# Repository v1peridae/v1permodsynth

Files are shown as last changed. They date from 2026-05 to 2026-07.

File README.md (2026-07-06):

# This is the v1permodsyth

- A modular sythesiser is an electronic music instrument made of different sythesiser modules! (who wouldve guessed)
- They look something like this:

<p align="center">
  <br>
  <sub>(mine doesn't look as fancy but we're getting somewhere lol)</sub>
</p>

### it currently has:
- square vco
  
  

- vca




- guitar input




-ar




-4lfo




-fm drums




## more on the process
i've never really made anything this complex so i totally understand if it might not work on the first go but i'm really happy with how far i've gotten with this. if you'd like to learn more about the making process check out my JOURNAL.md 

credits to https://www.bartonmusicalcircuits.com/ which is where i learnt how to do all of this :)

casing - it currently doesnt have a case but i have all the measurements and hope to build a wooden or hard cardboard case

note on commits:
guh it totally skipped my mind to make frequent commits of this so i accept my fate if it means my hours get reduced since this is one is on me.

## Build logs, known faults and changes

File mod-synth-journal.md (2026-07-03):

# mod synth! — Journal Export

- Exported at: 2026-07-03T07:13:49Z
- Project ID: 630
- Entries: 12

## Entry 1
- ID: 4969
- Author: lou
- Created At: 2026-01-08T16:54:00Z

### Content

I've always thought hardware to make music was pretty cool! I listen to lots of electronic music and this was specifically inspired by the modular synthesiser tracks by Aphex Twin and Autechre (and at some point Deadmau5 🫩 BUT I AM PAST THAT I PROMISE) 

If you're not familar, a modular Synthesiser looks like this:

Mine won't look as cool but you get the picture.

I've been doing the research on and off rather than in one continuous stream. In the research phase I was mainly learning about how the work under the hood and good starting components to begin with! YouTube has been the greatest helper with how the components work and [this](https://analogoutputblog.wordpress.com/synth-diy-repositories/) has been the greatest helper when it comes to figuring out DIY. I've also been looking at old resources like CGS and Eddy Bergman to figure more out especially on the DIY end :D

So I'm going to be making : 
1. Voltage-Controlled Oscillator
2. Low-Frequency Oscillator
3. Voltage-Controlled Amplifier
4. Voltage-Controlled Filter
5. Envelope Generator 

Obviously just to start since there's lots more I can add here.

I'm going to have a 12V Eurorack setup probably!

I played around with these in VCV Rack to get a taste of how they work!

## Entry 2
- ID: 4970
- Author: lou
- Created At: 2026-01-10T18:26:00Z

### Content

So I started building the VCO which is like the main part since it varies all the voltage.
I used this tutorial for the main stuff but tweaked it as you can see mostly because I didn't want to have as many THT parts and prefer SMD where possible :D It also involved lots of figuring out what does what since the docs aren't the MOSSST descriptive so I obviously messed up lots but I think I (MIGHT) have figured it out. Like one of the potentiometers is put as a var resistor symbol while the rest are potentiometers simply bc of the lack of the last connection. 

ALSO AMERICAN SYMBOLS ARE SO CONFUSING WHAT.

This is what the Schematic looks like 

In the future I might add more wave functions but square is a pretty good start!

This is what the routing looks like: 

Up next is the VCA!

## Entry 3
- ID: 4971
- Author: lou
- Created At: 2026-01-18T17:31:00Z

### Content

A VCA is an amplifier!!
I'm gonna seperate this into 2 parts, schematics then PCB. I used [this](https://www.bartonmusicalcircuits.com/vcamix/index.html) and [this](https://www.birthofasynth.com/Thomas_Henry/Pages/VCA-1.html). I can't lie it's been a little hard for this one lol but I think the schematics took far less time bc im now used to what I need to know. I also switched out parts for stuff JLC can assemble for me as much as i can but there are some parts that JCL just cant so I gotta do ts myself. 

Schematics thus far!



## Entry 4
- ID: 4972
- Author: lou
- Created At: 2026-01-19T14:52:00Z

### Content

So i just finished my VCA...
Let me start by saying HOLY ROUTING NIGHTMARE OH MY GOD. I have spent a sold 3 hours just trying to arrange the parts then route ts. This is what it looks like thus far! I have about 3 errors from DRC but im gonna assume those errors cant hurt me. I used the GND tutorial from the devboard which simplified my work so much more :))

I've been doing this for almost 4 days now so I am so glad I am done...up to the next thingamabob!



## Entry 5
- ID: 4973
- Author: lou
- Created At: 2026-01-30T20:32:00Z

### Content

Hi hi! So I worked on this guitar input. Idk if i'll be able to finish up everything else before Blueprint ends :heavysob: I just have so much to work on arggggg so I think for now I'll submit these. I also just realised I never put my stuff on Github and I will be hunted for sport by reviewers soon </3

I got help from [this](https://www.bartonmusicalcircuits.com/gtrin/documentation.pdf)

This was probably the easiest part so I finished it up within like 3 hours. I ALSO HAD NO ERRORS. NOTICE HOW LOCKED IN I AM???
 

Le schematic

Le PCB


## Entry 6
- ID: 4974
- Author: lou
- Created At: 2026-05-02T05:16:39Z

### Content

Project transferred from Blueprint! Duration Transferred: 18.0h

## Entry 7
- ID: 8107
- Author: lou
- Created At: 2026-05-20T07:32:42Z

### Content

i worked on the 4lfo. i'm getting the hang of this so i'm super happy this is getting quicker :) this is one of the easier components so it might take me a little under 3 hours to make but im happy i'm finally getting this done.

hard parts? mmmm i don't think there were actually any hard parts outside figuring out what the fuck american symbols mean :pf:

i also decided to use 4 layers for this one because it made routing easier. never done that before but i really enjoyed doing that.





### Recording Links

- https://lookout.hackclub.com/api/media/254f5015-b547-4b64-813b-f652eff59c81/video.mp4
- https://lookout.hackclub.com/api/media/c7d9977c-03ef-436e-be6a-447fcc133e85/video.mp4
- https://lookout.hackclub.com/api/media/2c16f990-9627-497f-b129-cb42529b9ac3/video.mp4
- https://lookout.hackclub.com/api/media/4dcfd294-e018-45b3-af8e-af4b0ad8f3b9/video.mp4
- https://lookout.hackclub.com/api/media/b42f091e-bb68-49f8-a317-3bbb6d3be94f/video.mp4

## Entry 8
- ID: 9162
- Author: lou
- Created At: 2026-05-25T17:51:06Z

### Content

i've been working on the schematics for my fm drum! it's designed to create unconventional and unnatural textures and synthetic percussion :) 
**here are the schematics**



i learnt alot from making this which means i have a lot to fix in my older stuff... mostly with some of the power supply stuff and the tl074/tl072.

will complete routing tmrw! 

im glad im getting faster and better at doing this :D

### Recording Links

- https://lookout.hackclub.com/api/media/666c798c-b988-48d3-a105-8d83bd73a606/video.mp4
- https://lookout.hackclub.com/api/media/1e7f963f-7c3f-451a-a312-f2ec80182804/video.mp4
- https://lookout.hackclub.com/api/media/89d17c2f-7477-4ceb-8acc-8d4e37869226/video.mp4

## Entry 9
- ID: 9452
- Author: lou
- Created At: 2026-05-26T19:25:01Z

### Content

hi hi! so i finished the fm drums and i'm currently using my newfound knowledge to fix my older pcbs (see prev devlog). here is the new fixed vco.



also the 17 min long log might be a lil shorter bc i was working from a cafe so i took eating breaks for like 30 seconds and all.

### Recording Links

- https://lookout.hackclub.com/api/media/01bfbfd5-133d-4821-b6bc-78ae78223fac/video.mp4
- https://lookout.hackclub.com/api/media/4d018d23-aed7-4f36-ab41-915f41100638/video.mp4
- https://lookout.hackclub.com/api/media/50de6fa7-70f4-43f6-9218-0a3cec68bf60/video.mp4

## Entry 10
- ID: 9659
- Author: lou
- Created At: 2026-05-27T14:17:05Z

### Content

fixed vca and added some decor :)

so i decided to fix my vca since and reroute it since after i changed the schematics all the routing turned out to be wrong. i also added some cute decor for the vca in the same style as the vco :)
Screenshot 2026-05-27 at 17.14.40.png

### Recording Links

- https://lookout.hackclub.com/api/media/017498c4-98fe-4673-93ac-65d4ebbb52b3/video.mp4
- https://lookout.hackclub.com/api/media/8d289a57-20fc-4ead-98d7-aa008f37cf2b/video.mp4
- https://lookout.hackclub.com/api/media/cd11847e-4ab6-44cd-961b-9dd82fdf83e7/video.mp4

## Entry 11
- ID: 9967
- Author: lou
- Created At: 2026-05-28T18:04:17Z

### Content

So i did some fixing on my guitar input and then added some decor so it's good to go now! Lots of cool learning from the previous day so i'm really glad i got to learn that theyre are different variants to the same unit since that has probably saved my entire system. next is adding a simple AR to my system which i've already started on (i'll journal about this in better detail one it's on)

Screenshot 2026-05-28 at 20.02.18.png
Screenshot 2026-05-28 at 20.01.55.png

### Recording Links

- https://lookout.hackclub.com/api/media/ef716bb8-1abb-4f87-9535-b88e8755269b/video.mp4
- https://lookout.hackclub.com/api/media/fd7e7cbc-a6ea-4806-a5a6-648855f2a1bf/video.mp4

## Entry 12
- ID: 10072
- Author: lou
- Created At: 2026-05-29T06:11:20Z

### Content

is the modsynth complete? ...yeah (for now). did some decor touches and tried to finish the AR as fast as i could. im really happy with all the progress i've made over time and being able to get from 5 hour builds with lots of mistakes to 1-2hr builds with minimal errors :). i've learnt a shit ton about kicad through this and the tutorials i followed. shout out to https://www.bartonmusicalcircuits.com/synthstuff.html for all the helpful resources about building a synth :D if it wasnt for their resources i would be super lost. although they werent very clear and i ended up fucking up a ton in the beginning, i got the hang of it and i'm done! i'm left with updating the github which i will later today and then i start on my next project :D

### today's progress...
Screenshot 2026-05-29 at 09.02.34.png

### Recording Links

- https://lookout.hackclub.com/api/media/206eb605-851f-4c07-8cec-c4d512dba3dc/video.mp4
- https://lookout.hackclub.com/api/media/da2813a5-71fb-49d3-a33c-df836aa85cb8/video.mp4

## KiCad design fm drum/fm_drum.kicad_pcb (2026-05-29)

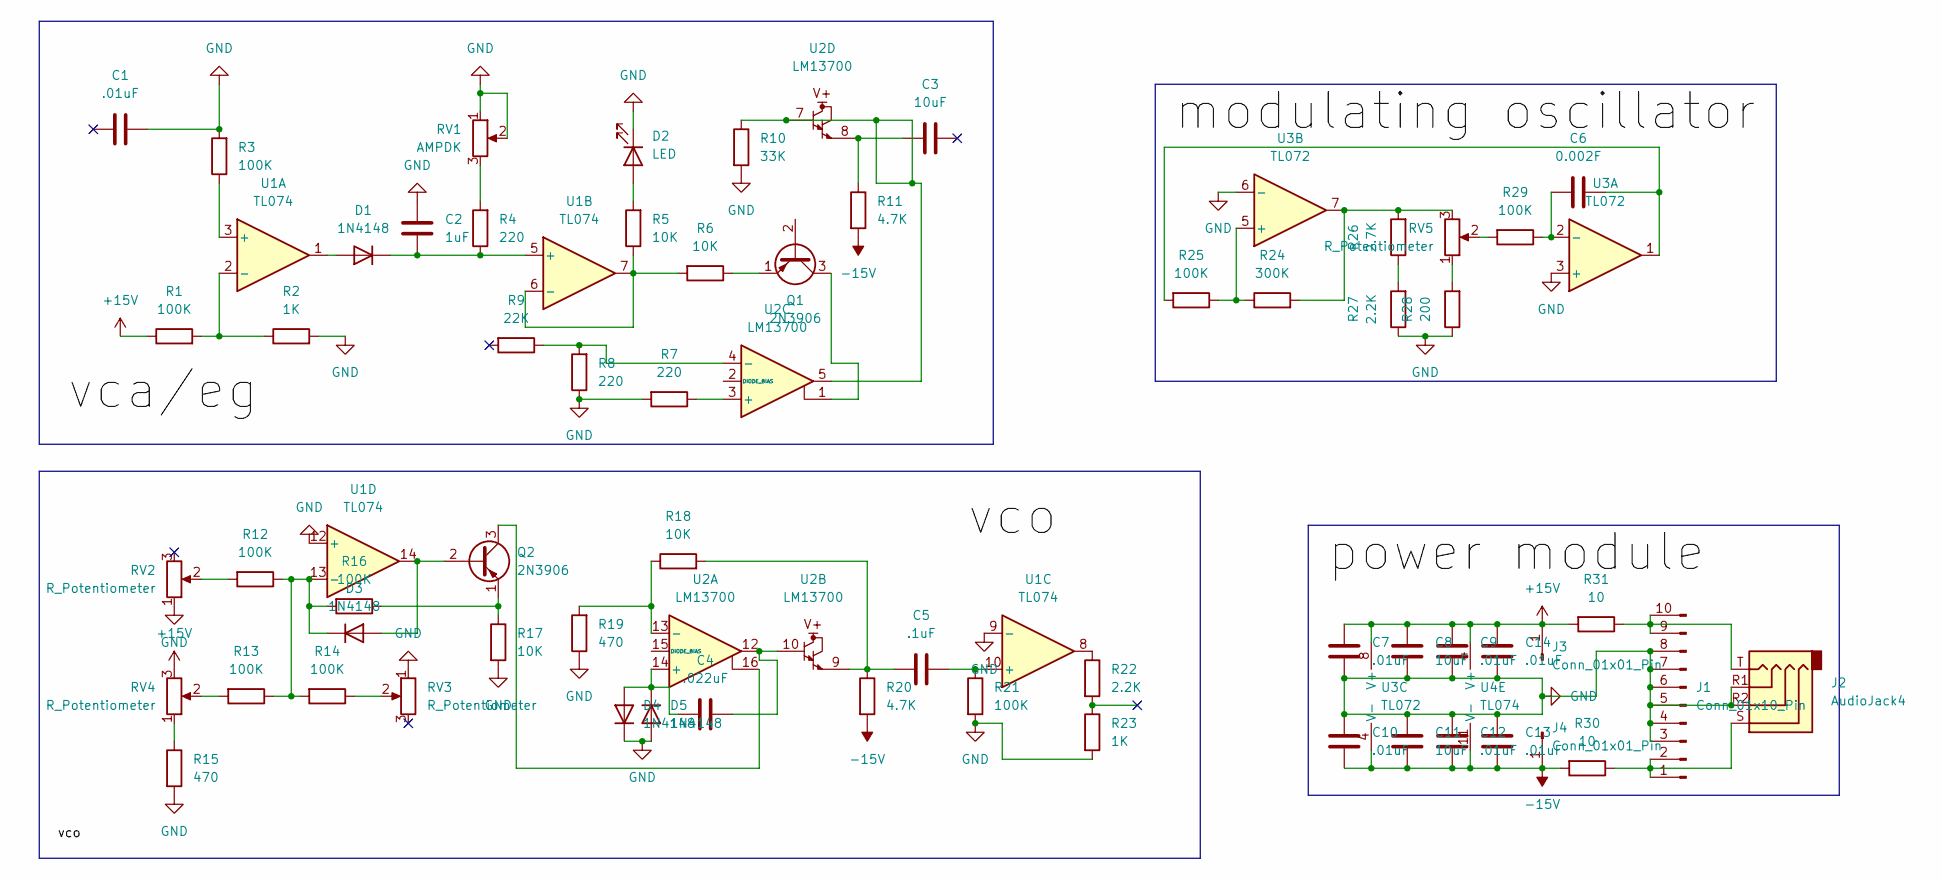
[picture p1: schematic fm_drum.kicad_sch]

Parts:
C1, C7, C9, C10, C12, C13, C14: .01uF; C_Disc_D3.8mm_W2.6mm_P2.50mm
C2: 1uF; CP_Radial_D5.0mm_P2.00mm
C3, C8, C11: 10uF; CP_Radial_D5.0mm_P2.50mm
C4: .022uF; C_Rect_L7.2mm_W2.5mm_P5.00mm_FKS2_FKP2_MKS2_MKP2
C5: .1uF; C_Rect_L7.2mm_W2.5mm_P5.00mm_FKS2_FKP2_MKS2_MKP2
C6: 0.002F; C_Rect_L7.2mm_W2.5mm_P5.00mm_FKS2_FKP2_MKS2_MKP2
D1, D3, D4, D5: 1N4148; D_DO-35_SOD27_P7.62mm_Horizontal
D2: LED; LED_D3.0mm
J1: Conn_01x10_Pin; IDC-Header_2x05_P2.54mm_Vertical
J2: AudioJack4; Jack_3.5mm_QingPu_WQP-PJ398SM_Vertical_CircularHoles
J3, J4: Conn_01x01_Pin; PinHeader_1x01_P2.54mm_Horizontal
Q1, Q2: 2N3906; TO-92_Inline
R1, R3, R12, R13, R14, R16, R21, R25, R29: 100K; R_Axial_DIN0207_L6.3mm_D2.5mm_P7.62mm_Horizontal
R2, R23: 1K; R_Axial_DIN0207_L6.3mm_D2.5mm_P7.62mm_Horizontal
R4, R7, R8: 220; R_Axial_DIN0207_L6.3mm_D2.5mm_P7.62mm_Horizontal
R5, R6, R17, R18: 10K; R_Axial_DIN0207_L6.3mm_D2.5mm_P7.62mm_Horizontal
R9: 22K; R_Axial_DIN0207_L6.3mm_D2.5mm_P7.62mm_Horizontal
R10: 33K; R_Axial_DIN0207_L6.3mm_D2.5mm_P7.62mm_Horizontal
R11, R20: 4.7K; R_Axial_DIN0207_L6.3mm_D2.5mm_P7.62mm_Horizontal
R15, R19: 470; R_Axial_DIN0207_L6.3mm_D2.5mm_P7.62mm_Horizontal
R22, R27: 2.2K; R_Axial_DIN0207_L6.3mm_D2.5mm_P7.62mm_Horizontal
R24: 300K; R_Axial_DIN0207_L6.3mm_D2.5mm_P7.62mm_Horizontal
R26: 2.7K; R_Axial_DIN0207_L6.3mm_D2.5mm_P7.62mm_Horizontal
R28: 200; R_Axial_DIN0207_L6.3mm_D2.5mm_P7.62mm_Horizontal
R30, R31: 10; R_Axial_DIN0207_L6.3mm_D2.5mm_P7.62mm_Horizontal
RV1: AMPDK; Potentiometer_Alps_RK163_Single_Horizontal
RV2, RV3, RV4, RV5: R_Potentiometer; Potentiometer_Alps_RK163_Single_Horizontal
U1, U4: TL074; DIP-14_W7.62mm
U2: LM13700; SOIC-16_3.9x9.9mm_P1.27mm
U3: TL072; DIP-8-16_W7.62mm

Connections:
+15V: C7.2, C8.2, C9.2, C14.2, J3.1, R1.1, R31.2, RV4.3, U3.8 (V+), U4.4 (V+)
-15V: C10.1, C11.1, C12.1, C13.1, J4.1, R11.2, R20.2, R30.2, U3.4 (V-), U4.11 (V-)
GND: C1.2, C2.2, C7.1, C8.1, C9.1, C10.2, C11.2, C12.2, C13.2, C14.1, D2.1 (K), D4.1 (K), D5.2 (A), J1.3, J1.4, J1.5, J1.6, J1.7, J1.8, J2.R1, J2.R2, R2.2, R3.2, R7.2, R8.1, R10.2, R15.2, R17.2, R19.1, R21.2, R23.2, R27.1, R28.1, RV1.1, RV1.2, RV2.1, RV3.1, U1.9 (-), U1.12 (+), U3.3 (+), U3.6 (-)
unnamed: C3.2, R11.1, U2.8
unnamed: C4.2, U2.10, U2.12
unnamed: C5.1, R18.2, R20.1, U2.9
unnamed: C6.2, R25.2, U3.1
unnamed: D1.2 (A), U1.1
unnamed: C2.1, D1.1 (K), R4.1, U1.5 (+)
unnamed: D2.2 (A), R5.2
unnamed: D3.2 (A), Q2.2 (B), U1.14
unnamed: D3.1 (K), R12.1, R13.1, R14.2, R16.2, U1.13 (-)
unnamed: C4.1, D4.2 (A), D5.1 (K), U2.14 (+)
unnamed: J1.1, J1.2, J2.S, R30.1
unnamed: J1.9, J1.10, J2.T, R31.1
unnamed: Q1.3 (C), U2.1
unnamed: Q1.1 (E), R6.1
unnamed: Q2.3 (C), U2.16
unnamed: Q2.1 (E), R16.1, R17.1
unnamed: R4.2, RV1.3
unnamed: R10.1, U2.5, U2.7
unnamed: R12.2, RV2.2
unnamed: R13.2, RV4.2
unnamed: R14.1, RV3.2
unnamed: R15.1, RV4.1
unnamed: R22.1, U1.8
unnamed: R24.2, R26.2, RV5.3, U3.7
unnamed: R26.1, R27.2
unnamed: R28.2, RV5.1
unnamed: R29.2, RV5.2
unnamed: R3.1, U1.3 (+)
unnamed: R1.2, R2.1, U1.2 (-)
unnamed: R5.1, R6.2, U1.6 (-), U1.7
unnamed: C5.2, R21.1, U1.10 (+)
unnamed: R18.1, R19.2, U2.13 (-)
unnamed: R7.1, U2.3 (+)
unnamed: R8.2, R9.1, U2.4 (-)
unnamed: C6.1, R29.1, U3.2 (-)
unnamed: R24.1, R25.1, U3.5 (+)

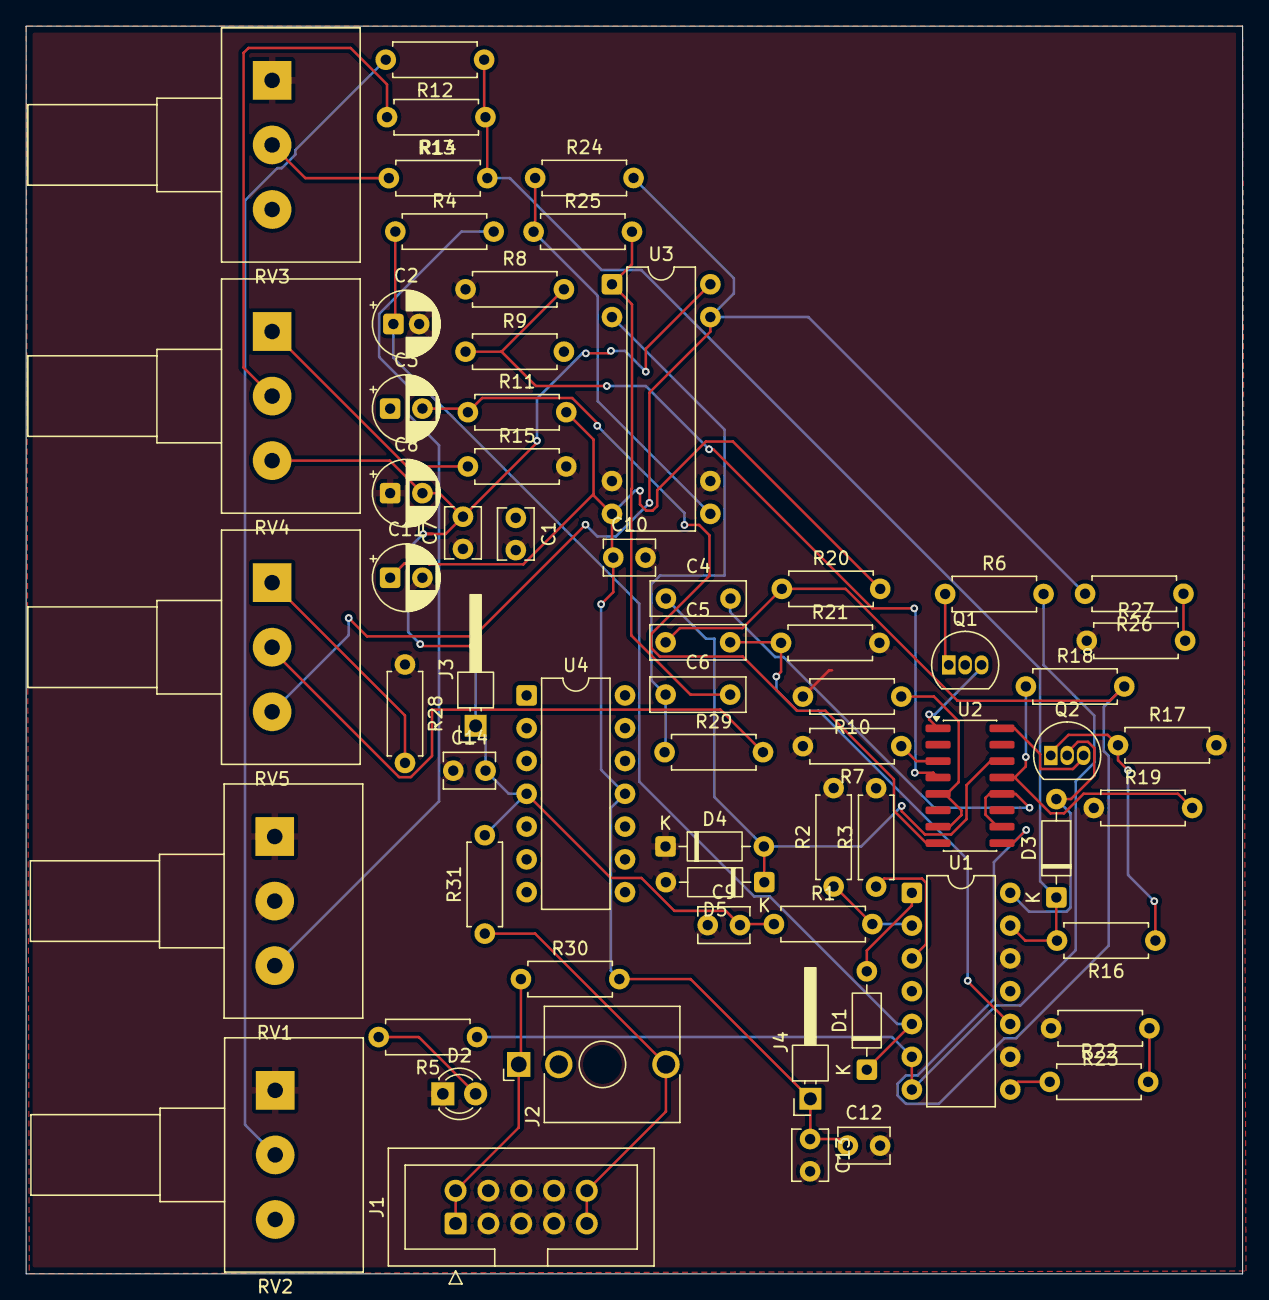
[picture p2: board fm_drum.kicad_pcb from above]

Board: 2 copper layers, 94.2 x 96.6 mm, 65 parts (0 on the bottom side), 39 nets.

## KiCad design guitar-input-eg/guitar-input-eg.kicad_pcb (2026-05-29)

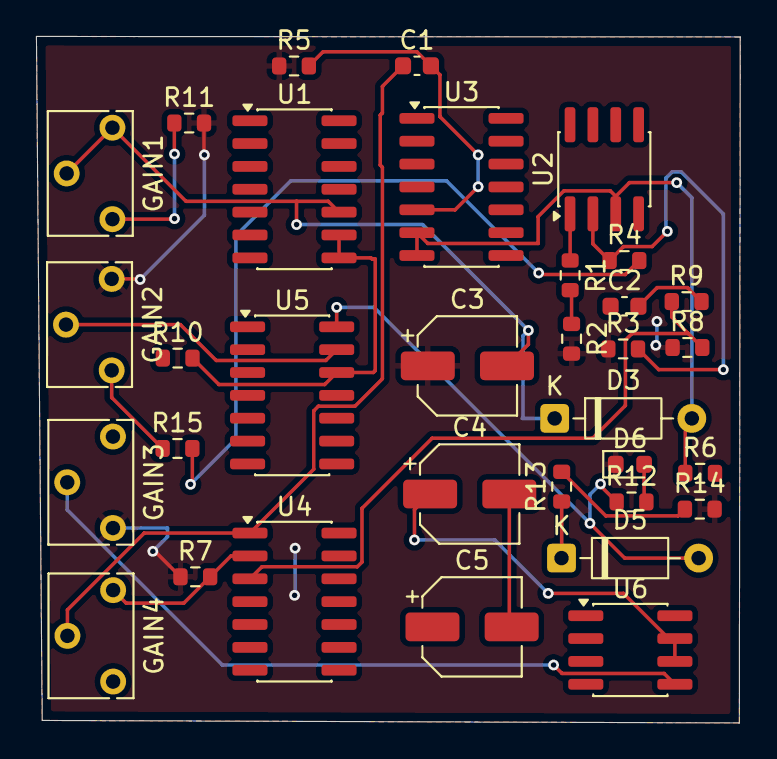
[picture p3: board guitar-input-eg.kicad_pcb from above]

Board: 2 copper layers, 39.1 x 38.1 mm, 34 parts (1 on the bottom side), 21 nets.

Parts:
.: LOGO
C1, C2: 1uF; C_0603_1608Metric
C3, C4, C5: 10uF; CP_Elec_5x5.4
D3, D5: 1N4148; D_DO-35_SOD27_P7.62mm_Horizontal
D6: LED; LED_0603_1608Metric
GAIN1, GAIN2, GAIN3, GAIN4: A1M; Potentiometer_Bourns_3266W_Vertical
R1, R13: 1.5K; R_0603_1608Metric
R2, R3, R6, R7, R10, R12, R14: 1K; R_0603_1608Metric
R4, R5, R8, R11, R15: 100K; R_0603_1608Metric
R9: 470K; R_0603_1608Metric
U1, U3, U4, U5: TL074; SOIC-14_3.9x8.7mm_P1.27mm
U2, U6: TL072; SOIC-8_3.9x4.9mm_P1.27mm

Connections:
+15V: R4.2, R15.2
GND: C3.1, D6.1 (K), GAIN2.3, GAIN3.1, R2.2, R3.1, R5.1, R7.1, R8.1, R11.2, R14.2
unnamed: C1.1, GAIN4.2, U4.1
unnamed: C2.2, R9.2
unnamed: C4.2, C5.2
unnamed: D3.2 (A), R6.1, U2.3 (+), U3.6 (-), U3.7
unnamed: C3.2, D3.1 (K), GAIN1.2, GAIN1.3, U1.10 (+)
unnamed: D5.2 (A), R12.1, U5.14
unnamed: D5.1 (K), R13.1
unnamed: D6.2 (A), R12.2
unnamed: GAIN1.1, R11.1
unnamed: GAIN2.1, R15.1
unnamed: R1.1, U2.1
unnamed: R10.2, U1.8, U1.9 (-), U5.12 (+)
unnamed: R3.2, R4.1, U2.2 (-)
unnamed: C1.2, R5.2, U3.5 (+)
unnamed: R8.2, R9.1, U4.3 (+)
unnamed: GAIN4.3, R7.2, U4.2 (-)
unnamed: GAIN2.2, U5.13 (-)
unnamed: GAIN3.2, U6.5 (+)
unnamed: C4.1, U6.6 (-), U6.7

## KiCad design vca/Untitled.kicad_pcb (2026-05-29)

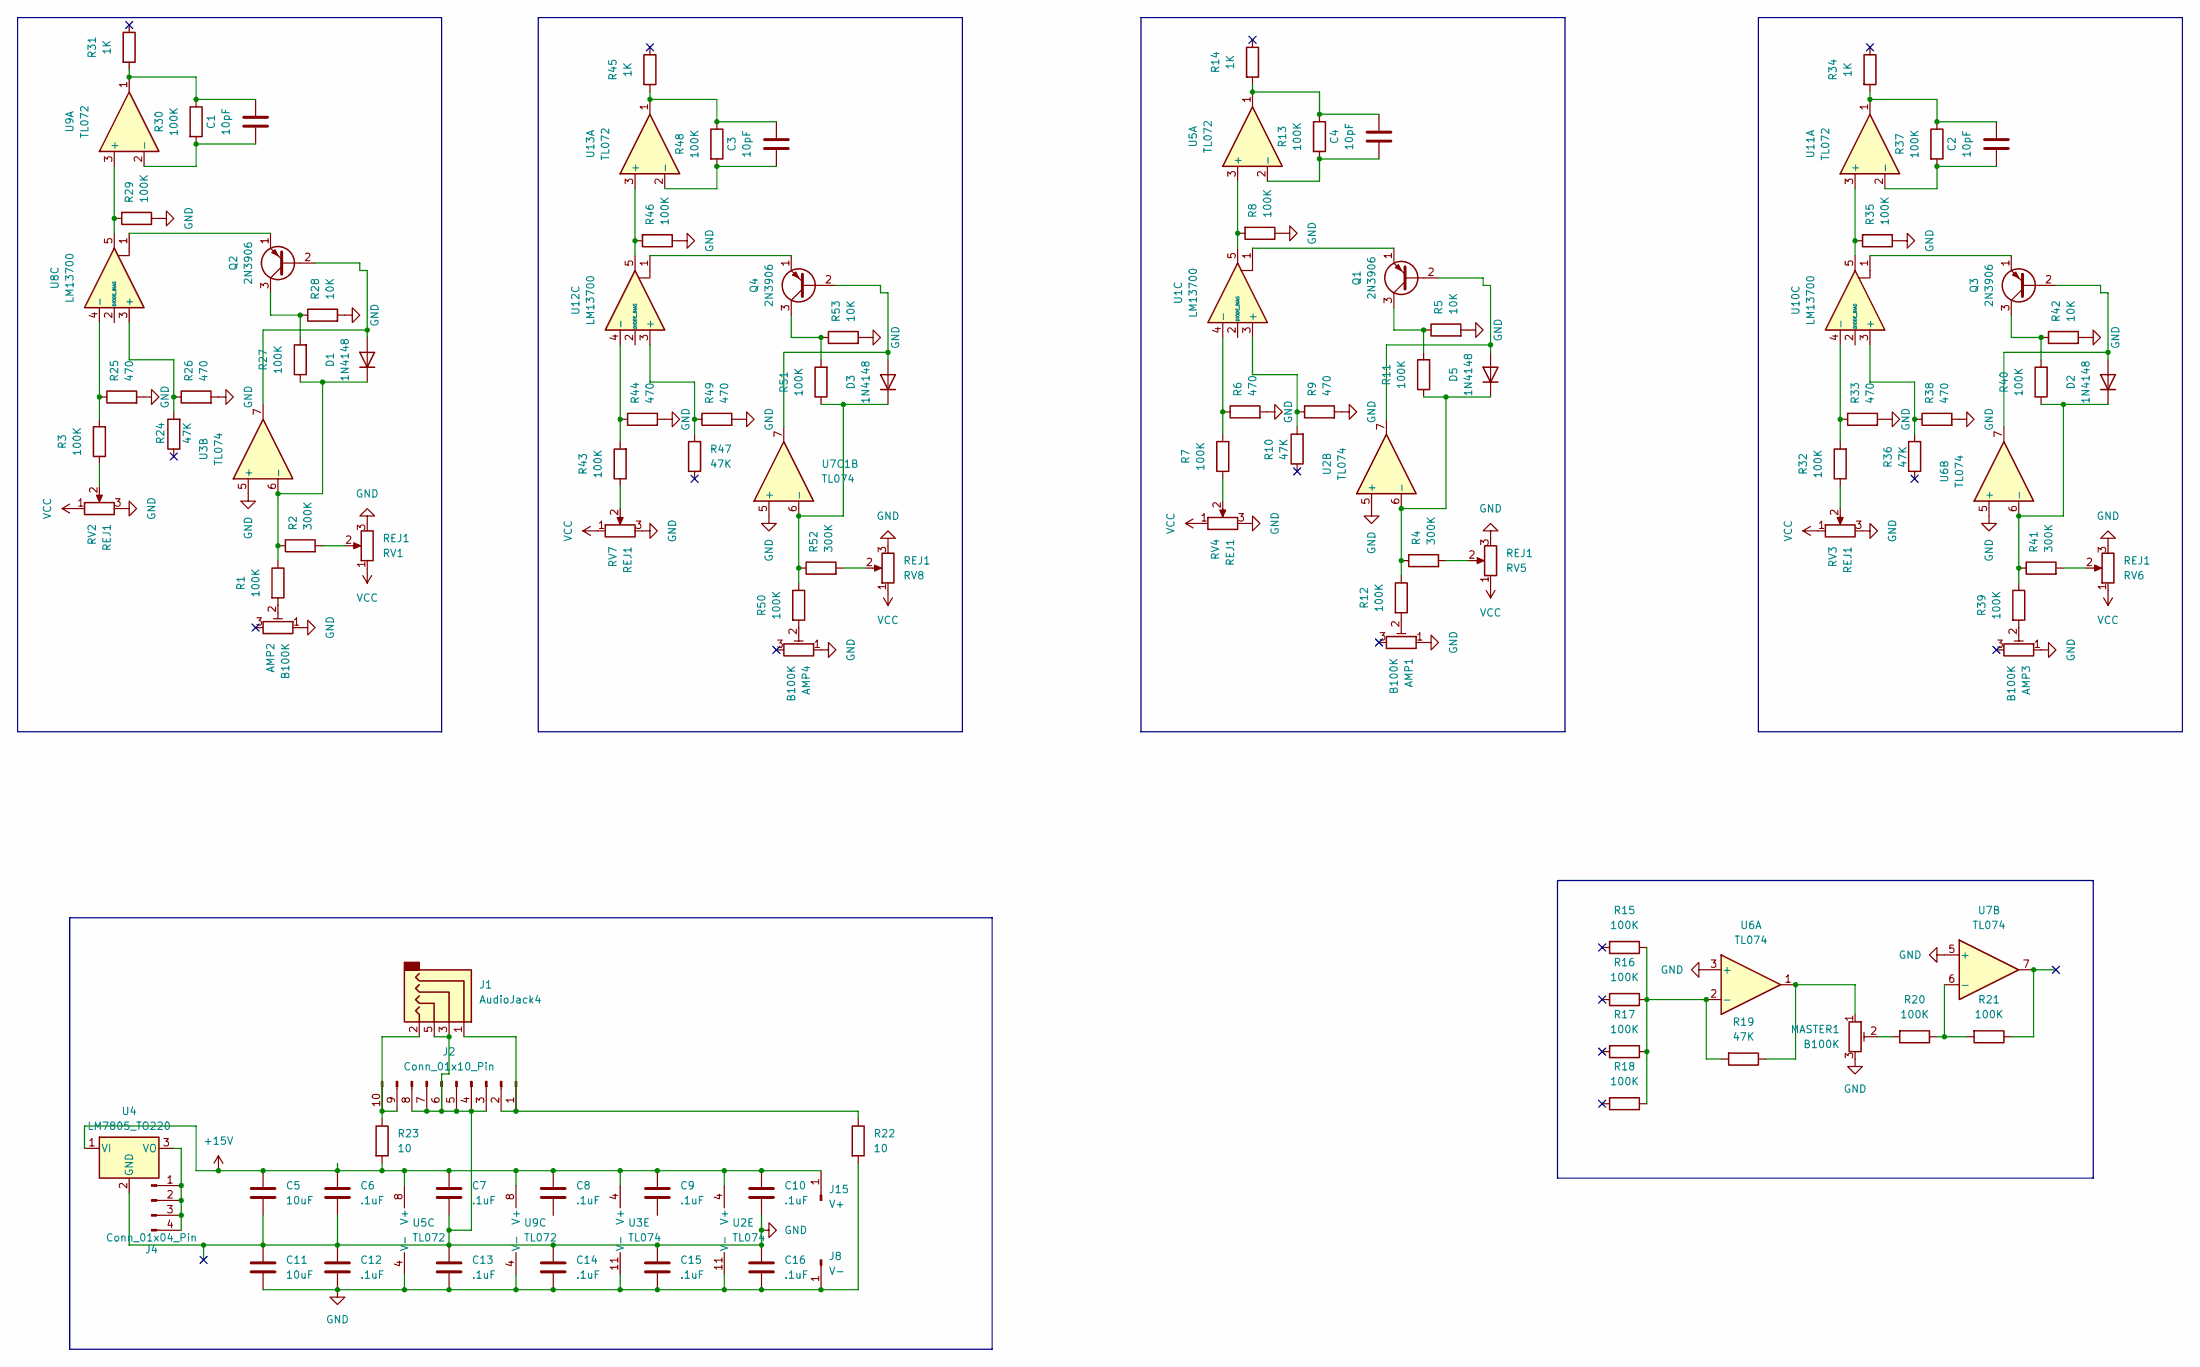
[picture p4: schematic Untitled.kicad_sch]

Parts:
AMP1, AMP2, AMP3, AMP4: B100K; Potentiometer_Bourns_3296W_Vertical
C1, C2, C3, C4: 10pF; CP_Elec_5x5.8
C5, C11: 10uF; CP_Elec_5x5.8
C6, C7, C8, C9, C10, C12, C13, C14, C15, C16: .1uF; C_0603_1608Metric
D1, D2, D3, D5: 1N4148; D_DO-35_SOD27_P7.62mm_Horizontal
J1: AudioJack4; Jack_3.5mm_PJ311_Horizontal
J2: Conn_01x10_Pin; IDC-Header_2x05_P2.54mm_Vertical_SMD
J4: Conn_01x04_Pin; PinHeader_1x04_P2.54mm_Vertical
J8: V-; PinHeader_1x01_P2.54mm_Vertical
J15: V+; PinHeader_1x01_P2.54mm_Vertical
MASTER1: B100K; Potentiometer_Bourns_3296W_Vertical
Q1, Q2, Q3, Q4: 2N3906; TO-92_Inline
R1, R3, R7, R8, R11, R12, R13, R15, R16, R17, R18, R20, R21, R27, R29, R30, R32, R35, R37, R39, R40, R43, R46, R48, R50, R51: 100K; R_0603_1608Metric
R2, R4, R41, R52: 300K; R_0603_1608Metric
R5, R28, R42, R53: 10K; R_0603_1608Metric
R6, R9, R25, R26, R33, R38, R44, R49: 470; R_0603_1608Metric
R10, R19, R24, R36, R47: 47K; R_0603_1608Metric
R14, R31, R34, R45: 1K; R_0603_1608Metric
R22, R23: 10; R_0603_1608Metric
RV1, RV2, RV3, RV4, RV5, RV6, RV7, RV8: REJ1; Potentiometer_Bourns_3269P_Horizontal
U1, U8, U10, U12: LM13700; SOIC-16_3.9x9.9mm_P1.27mm
U2, U3, U6, U7, U7C1: TL074; SOIC-14_3.9x8.7mm_P1.27mm
U4: LM7805_TO220; TO-220-3_Vertical
U5, U9, U11, U13: TL072; SOIC-8_3.9x4.9mm_P1.27mm

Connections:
+15V: C5.1, C6.1, C7.1, C8.1, C9.1, C10.1, J15.1, R23.2, U2.4 (V+), U3.4 (V+), U4.1 (VI), U5.8 (V+), U9.8 (V+); also elsewhere on the board
GND: AMP1.1, AMP2.1, AMP3.1, AMP4.1, C5.2, C6.2, C7.2, C10.2, C11.1, C11.2, C12.1, C12.2, C13.1, C13.2, C14.1, C14.2, C15.1, C15.2, C16.1, C16.2, J1.3, J1.5, J2.3, J2.4, J2.5, J2.6, J2.7, J2.8, J8.1, MASTER1.3, R5.2, R6.2, R8.1, R9.2, R22.2, R25.2, R26.2, R28.2, R29.1, R33.2, R35.1, R38.2, R42.2, R44.2, R46.1, R49.2, R53.2, RV1.3, RV2.3, RV3.3, RV4.3, RV5.3, RV6.3, RV7.3, RV8.3, U2.5 (+), U2.11 (V-), U3.5 (+), U3.11 (V-), U4.2 (GND), U5.4 (V-), U6.3 (+), U6.5 (+), U7.5 (+), U7C1.5 (+), U9.4 (V-); also elsewhere on the board
unnamed: AMP1.2, R12.2
unnamed: AMP2.2, R1.2
unnamed: AMP3.2, R39.2
unnamed: AMP4.2, R50.2
unnamed: C1.2, R30.1, R31.2, U9.1
unnamed: C2.2, R34.2, R37.1, U11.1
unnamed: C3.2, R45.2, R48.1, U13.1
unnamed: C4.2, R13.1, R14.2, U5.1
unnamed: D1.2 (A), Q2.2 (B), U3.7
unnamed: D1.1 (K), R1.1, R2.1, R27.1, U3.6 (-)
unnamed: D2.2 (A), Q3.2 (B), U6.7
unnamed: D2.1 (K), R39.1, R40.1, R41.1, U6.6 (-)
unnamed: D3.2 (A), Q4.2 (B), U7C1.7
unnamed: D3.1 (K), R50.1, R51.1, R52.1, U7C1.6 (-)
unnamed: D5.2 (A), Q1.2 (B), U2.7
unnamed: D5.1 (K), R4.1, R11.1, R12.1, U2.6 (-)
unnamed: J1.1, J2.1, J2.2, R22.1
unnamed: J1.2, J2.9, J2.10, R23.1
unnamed: J4.1, J4.2, J4.3, J4.4, U4.3 (VO)
unnamed: MASTER1.1, R19.1, U6.1
unnamed: MASTER1.2, R20.2
unnamed: Q1.3 (C), R5.1, R11.2
unnamed: Q1.1 (E), U1.1
unnamed: Q2.3 (C), R27.2, R28.1
unnamed: Q2.1 (E), U8.1
unnamed: Q3.3 (C), R40.2, R42.1
unnamed: Q3.1 (E), U10.1
unnamed: Q4.3 (C), R51.2, R53.1
unnamed: Q4.1 (E), U12.1
unnamed: R2.2, RV1.2
unnamed: R3.1, RV2.2
unnamed: R4.2, RV5.2
unnamed: R7.1, RV4.2
unnamed: R32.1, RV3.2
unnamed: R41.2, RV6.2
unnamed: R43.1, RV7.2
unnamed: R52.2, RV8.2
unnamed: R9.1, R10.2, U1.3 (+)
unnamed: R6.1, R7.2, U1.4 (-)
unnamed: R8.2, U1.5, U5.3 (+)
unnamed: C4.1, R13.2, U5.2 (-)
unnamed: R15.1, R16.1, R17.1, R18.1, R19.2, U6.2 (-)
unnamed: R20.1, R21.2, U7.6 (-)
unnamed: R24.2, R26.1, U8.3 (+)
unnamed: R3.2, R25.1, U8.4 (-)
unnamed: R29.2, U8.5, U9.3 (+)
unnamed: C1.1, R30.2, U9.2 (-)
unnamed: R36.2, R38.1, U10.3 (+)
unnamed: R32.2, R33.1, U10.4 (-)
unnamed: R35.2, U10.5, U11.3 (+)
unnamed: C2.1, R37.2, U11.2 (-)
unnamed: R47.2, R49.1, U12.3 (+)
unnamed: R43.2, R44.1, U12.4 (-)
unnamed: R46.2, U12.5, U13.3 (+)
unnamed: C3.1, R48.2, U13.2 (-)
VCC: RV1.1, RV2.1, RV3.1, RV4.1, RV5.1, RV6.1, RV7.1, RV8.1

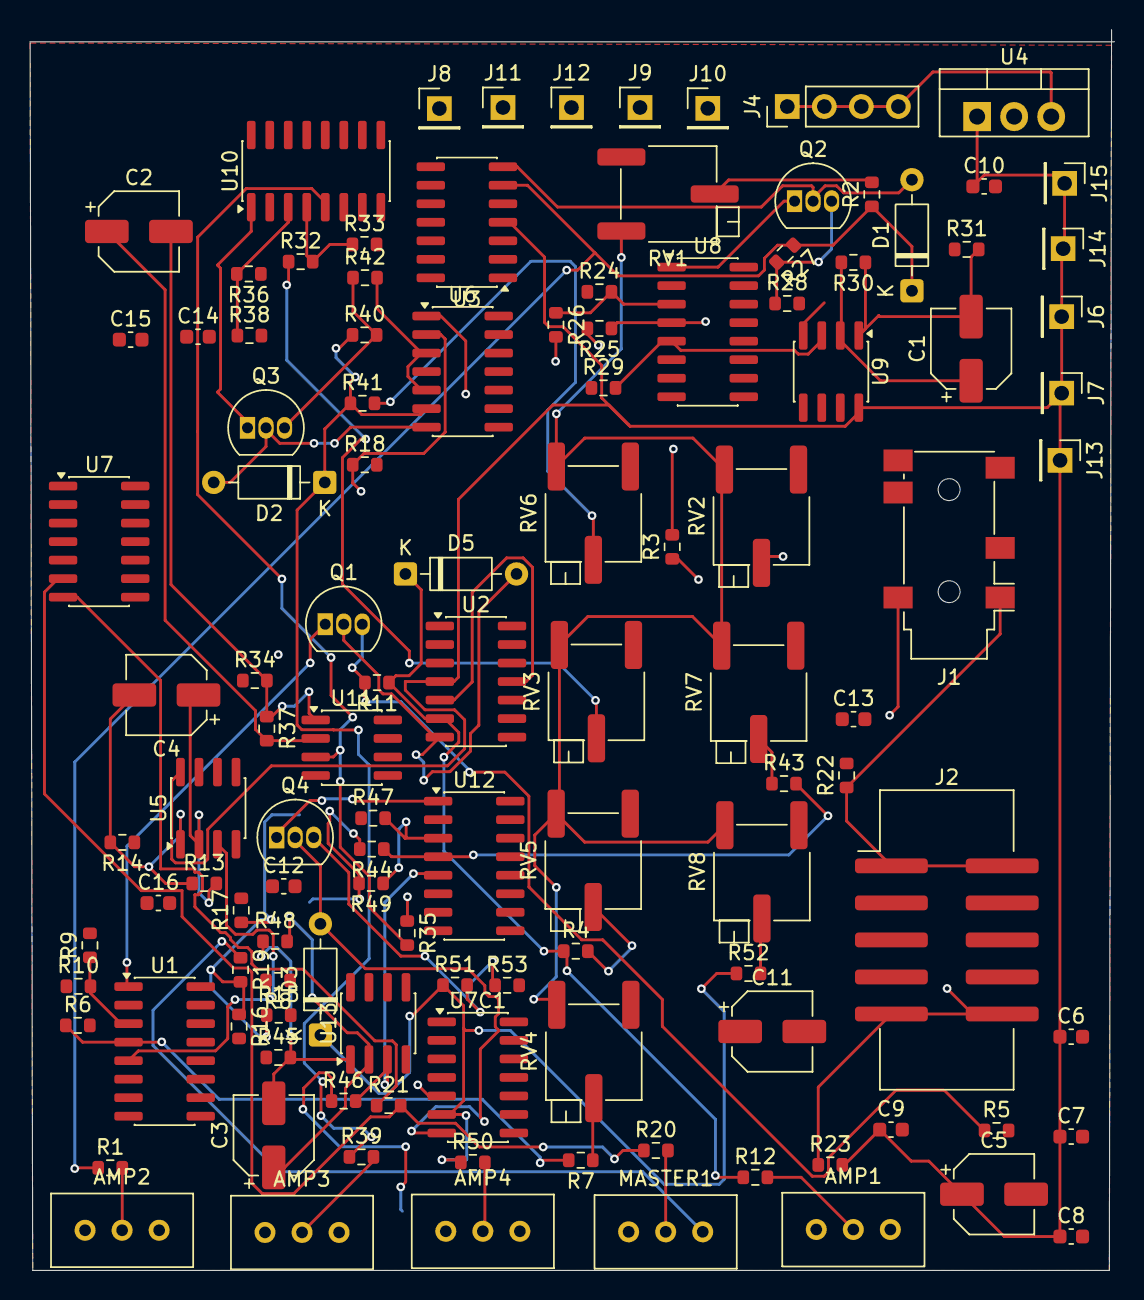
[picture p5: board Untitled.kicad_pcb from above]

Board: 4 copper layers, 74.4 x 85.1 mm, 117 parts (0 on the bottom side), 58 nets.

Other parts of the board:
J6, J7, J13, J14: V+; PinHeader_1x01_P2.54mm_Vertical
J9, J10, J11, J12: V-; PinHeader_1x01_P2.54mm_Vertical

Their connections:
+15V: J6.1, J7.1, J13.1, J14.1; also elsewhere on the board
GND: J9.1, J10.1, J11.1, J12.1; also elsewhere on the board

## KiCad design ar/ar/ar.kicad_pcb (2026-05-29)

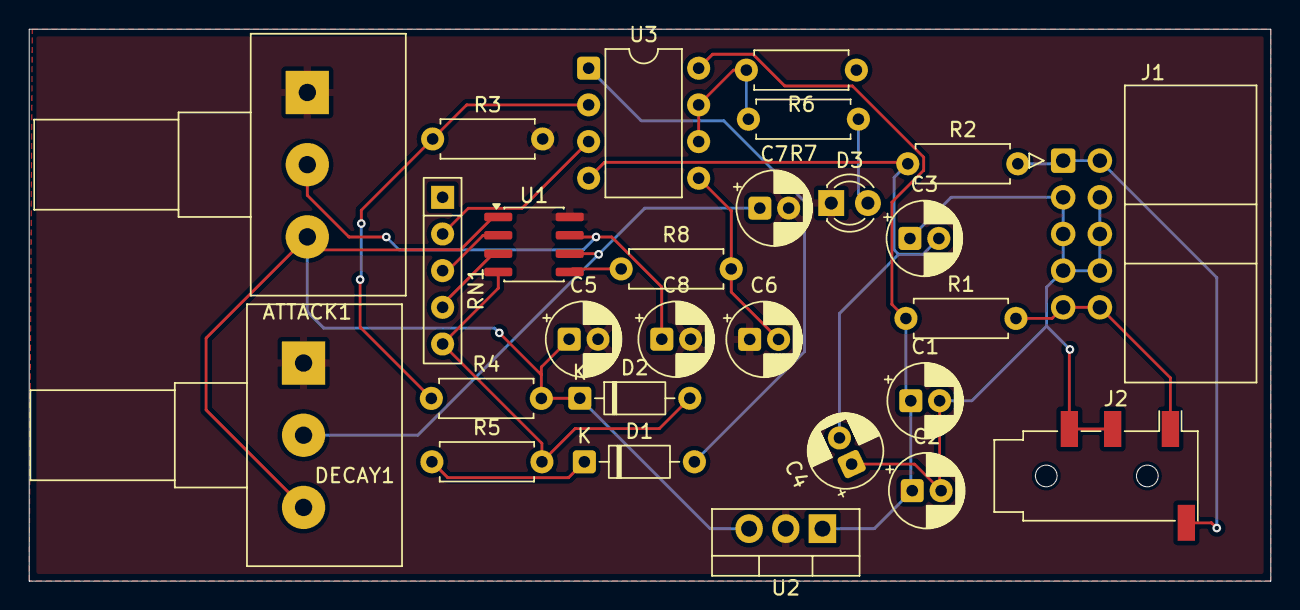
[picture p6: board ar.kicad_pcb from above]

Board: 2 copper layers, 86.0 x 38.2 mm, 27 parts (0 on the bottom side), 18 nets.

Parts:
ATTACK1: B100K; Potentiometer_Alps_RK163_Single_Horizontal
C1, C3: 10uF; CP_Radial_D5.0mm_P2.00mm
C2, C4, C5, C7, C8: 0.01uF; CP_Radial_D5.0mm_P2.00mm
C6: 0.1uF; CP_Radial_D5.0mm_P2.00mm
D1: 1N4148; D_DO-35_SOD27_P7.62mm_Horizontal
D2: D_Schottky; D_DO-35_SOD27_P7.62mm_Horizontal
D3: LED; LED_D3.0mm
DECAY1: B100K; Potentiometer_Alps_RK163_Single_Horizontal
J1: Conn_01x10_Pin; IDC-Header_2x05_P2.54mm_Horizontal
J2: AudioJack4; Jack_3.5mm_PJ320D_Horizontal
R1, R2: 10; R_Axial_DIN0207_L6.3mm_D2.5mm_P7.62mm_Horizontal
R3, R4, R5: 100K; R_Axial_DIN0207_L6.3mm_D2.5mm_P7.62mm_Horizontal
R6, R7: 1K; R_Axial_DIN0207_L6.3mm_D2.5mm_P7.62mm_Horizontal
R8: 33K; R_Axial_DIN0207_L6.3mm_D2.5mm_P7.62mm_Horizontal
RN1: 100K; R_Array_SIP5
U1: PIC12F683-xSN; SOIC-8_3.9x4.9mm_P1.27mm
U2: L7805; TO-220-3_Vertical
U3: TL072; DIP-8_W7.62mm

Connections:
+5V: ATTACK1.3, C5.1, D2.1 (K), DECAY1.3, R4.2, U1.1 (VDD), U2.3 (OUT)
GND: ATTACK1.1, C5.2, C6.1, C7.2, C8.2, D3.1 (K), DECAY1.1, R3.2, U1.8 (VSS), U2.2 (GND)
unnamed: D1.2 (A), U3.1
unnamed: D1.1 (K), R5.1
unnamed: D2.2 (A), R5.2, RN1.5 (R4), U1.4 (GP3)
unnamed: D3.2 (A), R7.1
unnamed: J1.1, J1.2, J2.S, R2.2
unnamed: C1.2, C2.2, C3.1, C4.1, J1.3, J1.4, J1.5, J1.6, J1.7, J1.8, J2.R1, J2.R2
unnamed: J1.9, J1.10, J2.T, R1.2
unnamed: RN1.2 (R1), U3.3 (+)
unnamed: ATTACK1.2, C8.1, U1.7 (GP0)
unnamed: C7.1, DECAY1.2, U1.6 (GP1)
unnamed: R8.1, U1.5 (GP2)
unnamed: C1.1, C2.1, R1.1, U2.1 (IN), U3.8 (V+)
unnamed: R3.1, R4.1, U3.2 (-)
unnamed: C6.2, R8.2, U3.5 (+)
unnamed: R6.2, R7.2, U3.6 (-), U3.7
unnamed: C3.2, C4.2, R2.1, U3.4 (V-)

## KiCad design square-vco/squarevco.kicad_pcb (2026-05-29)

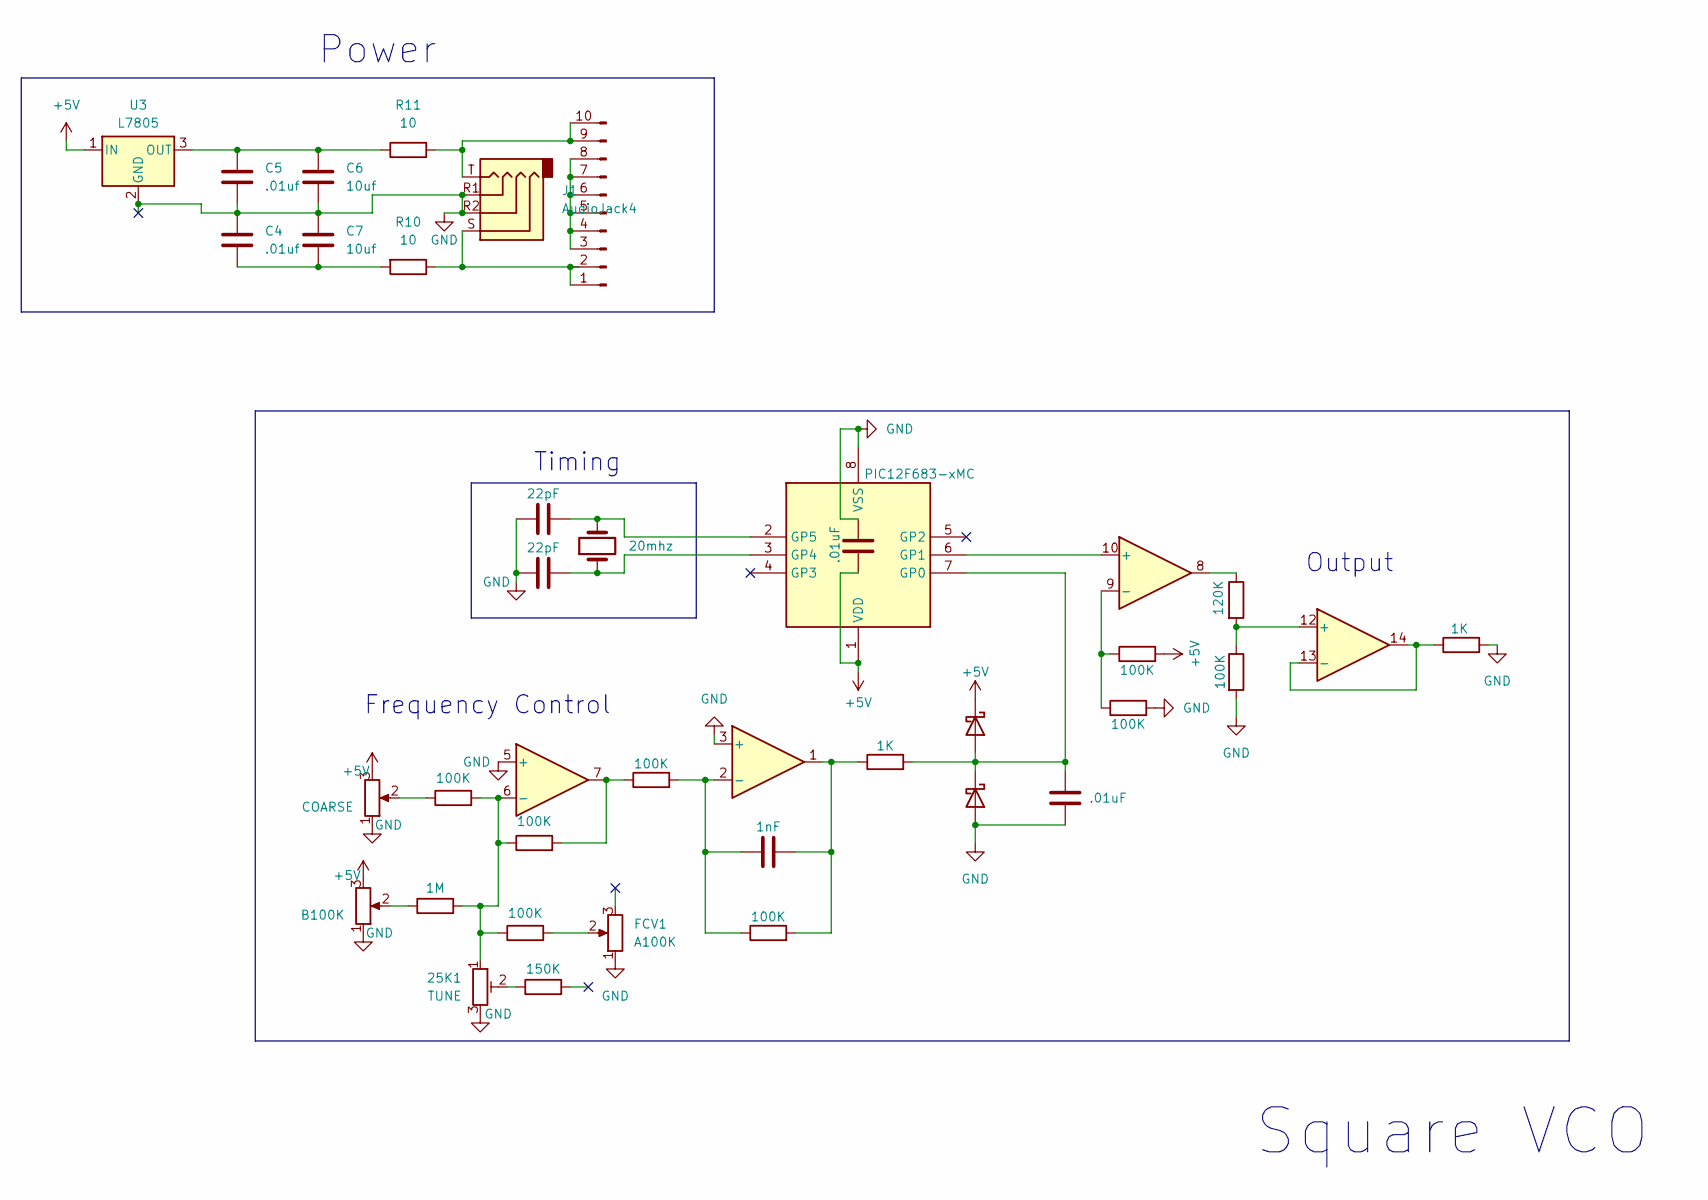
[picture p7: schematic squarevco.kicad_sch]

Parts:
25K1: TUNE; Potentiometer_Bourns_3269W_Vertical
B100K1: COARSE; Potentiometer_Alpha_RD901F-40-00D_Single_Vertical
C1, C9: 22pF; C_0805_2012Metric
C2: 1nF; C_0805_2012Metric
C3, C8: .01uF; C_0805_2012Metric
C4, C5: .01uf; C_0805_2012Metric
C6, C7: 10uf; CP_Elec_5x5.4
D1, D2: D_Schottky; D_SOD-123
FCV1: A100K; Potentiometer_Alpha_RD901F-40-00D_Single_Vertical
FINE1: B100K; Potentiometer_Alpha_RD901F-40-00D_Single_Vertical
J1: AudioJack4; Jack_3.5mm_QingPu_WQP-PJ398SM_Vertical_CircularHoles
J4: Conn_01x10_Pin; IDC-Header_2x05_P2.54mm_Horizontal
R1: 120K; R_0805_2012Metric
R2, R5, R7, R8, R14, R16, R17, R18: 100K; R_0805_2012Metric
R3, R4: 1K; R_0805_2012Metric
R6: 1M; R_0805_2012Metric
R10, R11: 10; R_0805_2012Metric
R19: 150K; R_0805_2012Metric
U1: PIC12F683-xMC; SOIC-8_3.9x4.9mm_P1.27mm
U2, U4, U5, U6: TL074; SOIC-14_3.9x8.7mm_P1.27mm
U3: L7805; SOT-223-3_TabPin2
Y1: 20mhz; Crystal_SMD_5032-2Pin_5.0x3.2mm

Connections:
+5V: B100K1.3, C8.2, D1.1 (K), FINE1.3, R7.2, U1.1 (VDD), U3.1 (IN)
GND: 25K1.3, B100K1.1, C1.2, C3.2, C4.1, C5.2, C6.2, C7.1, C8.1, C9.1, D2.2 (A), FCV1.1, FINE1.1, J1.R1, J1.R2, R2.2, R3.2, R8.2, U1.8 (VSS), U3.2 (GND), U5.5 (+), U6.3 (+); also elsewhere on the board
unnamed: 25K1.2, R19.1
unnamed: B100K1.2, R17.1
unnamed: C2.2, R4.1, R5.2, U6.1
unnamed: C4.2, C7.2, R10.2
unnamed: C3.1, D1.2 (A), D2.1 (K), R4.2, U1.7 (GP0)
unnamed: FCV1.2, R18.2
unnamed: FINE1.2, R6.1
unnamed 9: J1.S, J4.1, J4.2, R10.1; also elsewhere on the board
unnamed: J4.3, J4.4, J4.5, J4.6, J4.7, J4.8
unnamed 11: J1.T, J4.9, J4.10, R11.2; also elsewhere on the board
unnamed: R1.1, U2.8
unnamed: R14.1, R16.2, U5.7
unnamed: U1.6 (GP1), U2.10 (+)
unnamed: C1.1, U1.3 (GP4), Y1.1
unnamed: C9.2, U1.2 (GP5), Y1.2
unnamed: R7.1, R8.1, U2.9 (-)
unnamed: C5.1, C6.1, R11.1, U3.3 (OUT)
unnamed: R1.2, R2.1, U4.12 (+)
unnamed: R3.1, U4.13 (-), U4.14
unnamed: 25K1.1, R6.2, R16.1, R17.2, R18.1, U5.6 (-)
unnamed: C2.1, R5.1, R14.2, U6.2 (-)

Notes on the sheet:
Power
Timing
Frequency Control
Square VCO
Output

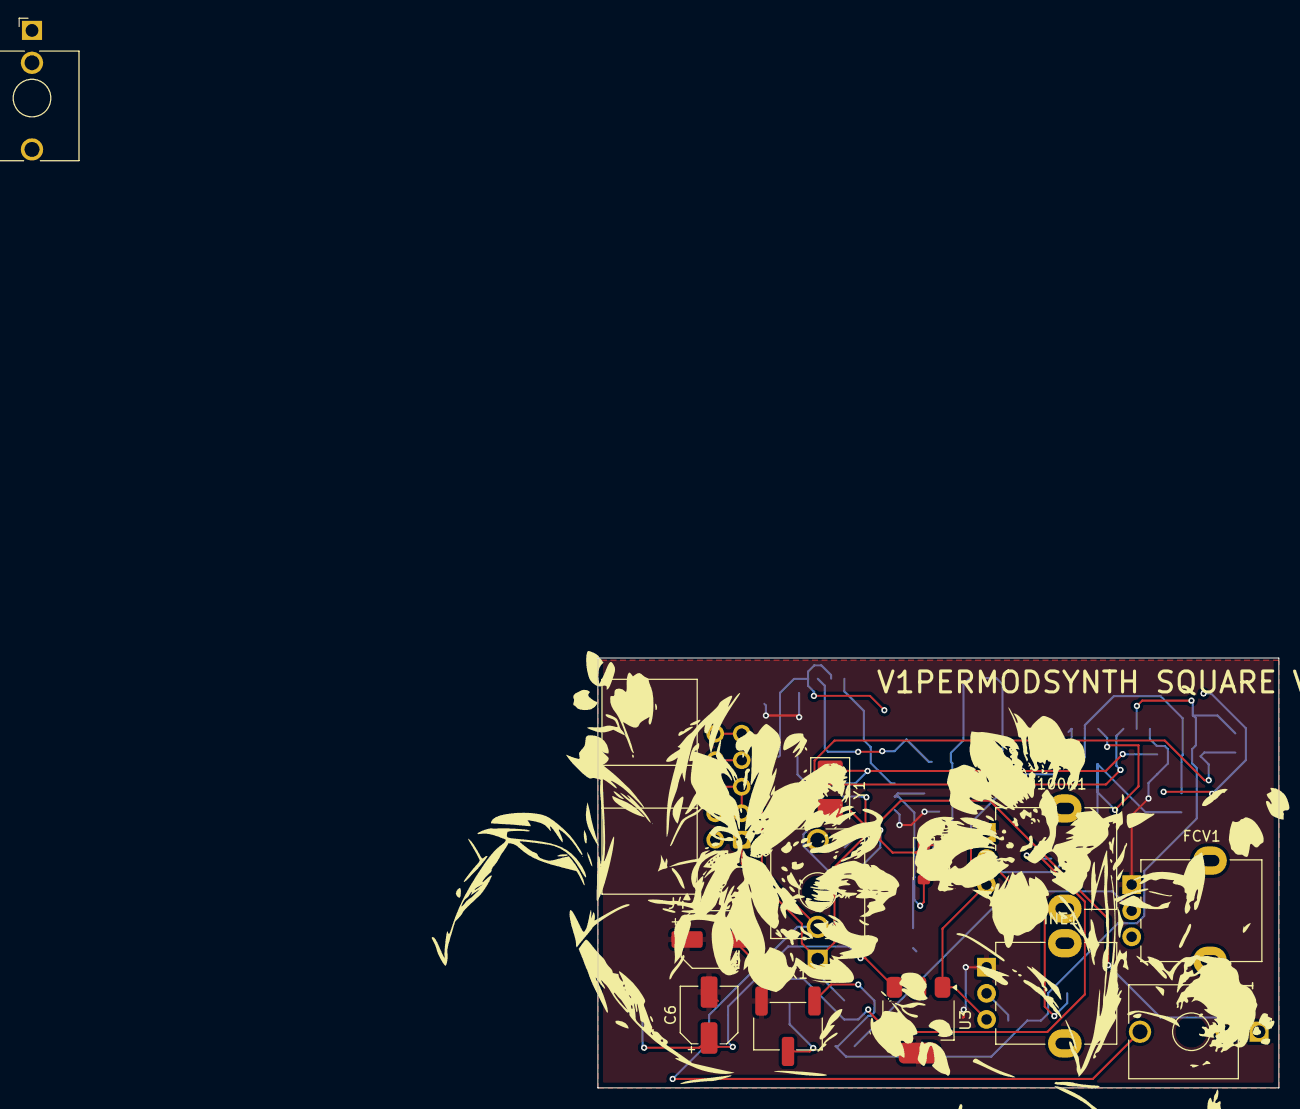
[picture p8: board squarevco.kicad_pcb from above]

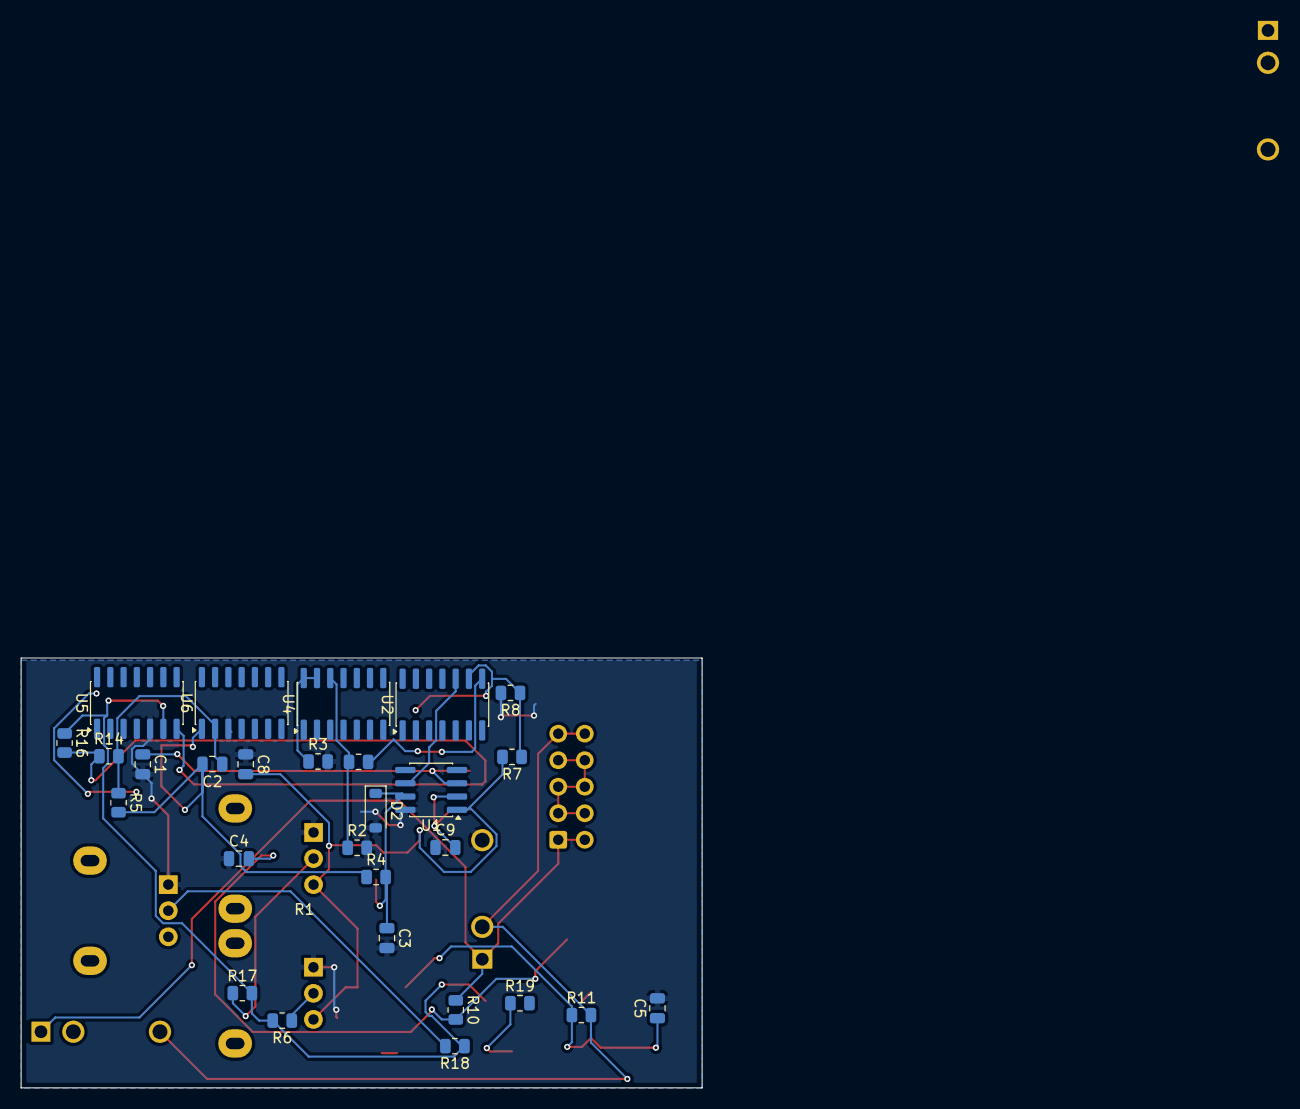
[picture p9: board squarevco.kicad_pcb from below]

Board: 2 copper layers, 65.2 x 41.2 mm, 41 parts (28 on the bottom side), 23 nets.

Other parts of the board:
J1#2: AudioJack2_Dual_Switch; Jack_3.5mm_QingPu_WQP-PJ398SM_Vertical_CircularHoles
J5: AudioJack3_SwitchT; Jack_3.5mm_QingPu_WQP-PJ398SM_Vertical_CircularHoles

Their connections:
GND: J5.T; also elsewhere on the board
unnamed 9: J5.S; also elsewhere on the board
unnamed 11: J5.TN; also elsewhere on the board

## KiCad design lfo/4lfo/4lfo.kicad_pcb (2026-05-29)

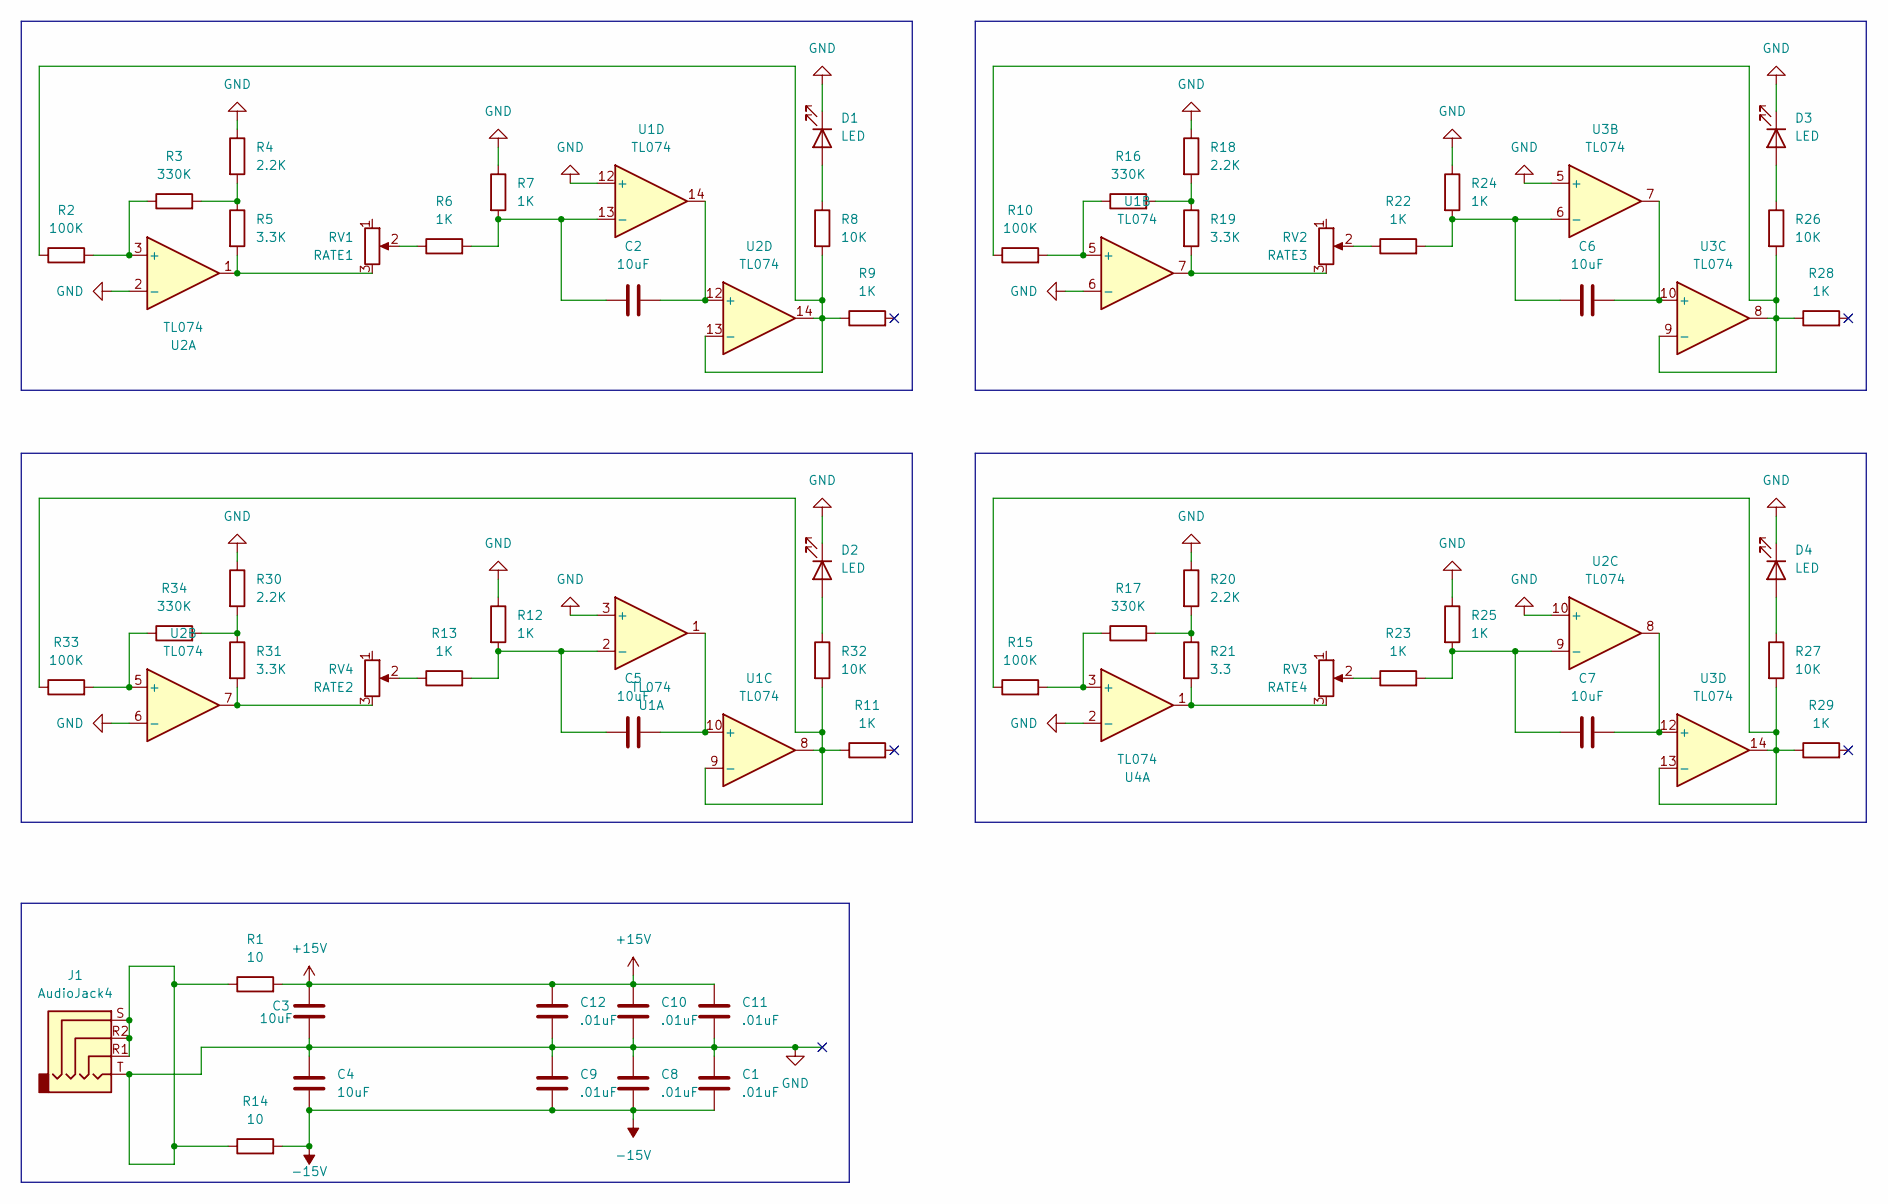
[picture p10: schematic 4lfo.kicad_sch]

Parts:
C1, C8, C9, C10, C11, C12: .01uF; C_0805_2012Metric
C2, C3, C4, C5, C6, C7: 10uF; C_1206_3216Metric
D1, D2, D3, D4: LED; LED_1206_3216Metric
J1: AudioJack4; Jack_3.5mm_QingPu_WQP-PJ398SM_Vertical_CircularHoles
R1, R14: 10; R_0805_2012Metric
R2, R10, R15, R33: 100K; R_0805_2012Metric
R3, R16, R17, R34: 330K; R_0805_2012Metric
R4, R18, R20, R30: 2.2K; R_0805_2012Metric
R5, R19, R31: 3.3K; R_0805_2012Metric
R6, R7, R9, R11, R12, R13, R22, R23, R24, R25, R28, R29: 1K; R_0805_2012Metric
R8, R26, R27, R32: 10K; R_0805_2012Metric
R21: 3.3; R_0805_2012Metric
RV1: RATE1; SOIC-14_3.9x8.7mm_P1.27mm
RV2: RATE3; SOIC-14_3.9x8.7mm_P1.27mm
RV3: RATE4; SOIC-14_3.9x8.7mm_P1.27mm
RV4: RATE2; SOIC-14_3.9x8.7mm_P1.27mm
U1, U2, U3, U4: TL074; SOIC-14_3.9x8.7mm_P1.27mm

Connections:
+15V: C3.2, C10.1, C11.1, C12.1, R1.2
-15V: C1.2, C4.2, C8.2, C9.2, R14.2
GND: C1.1, C3.1, C4.1, C8.1, C9.1, C10.2, C11.2, C12.2, D1.1 (K), D2.1 (K), D3.1 (K), D4.1 (K), J1.R1, J1.R2, J1.S, J1.T, R1.1, R4.1, R7.1, R12.1, R14.1, R18.1, R20.1, R24.1, R25.1, R30.1, U1.3 (+), U1.6 (-), U1.12 (+), U2.2 (-), U2.6 (-), U2.10 (+), U3.5 (+), U4.2 (-)
unnamed: D1.2 (A), R8.1
unnamed: D2.2 (A), R32.1
unnamed: D3.2 (A), R26.1
unnamed: D4.2 (A), R27.1
unnamed: R3.2, R4.2, R5.1
unnamed: R5.2, RV1.3, U2.1
unnamed: R6.1, RV1.2
unnamed: R13.1, RV4.2
unnamed: R16.2, R18.2, R19.1
unnamed: R17.2, R20.2, R21.1
unnamed: R19.2, RV2.3, U1.7
unnamed: R21.2, RV3.3, U4.1
unnamed: R22.1, RV2.2
unnamed: R23.1, RV3.2
unnamed: R30.2, R31.1, R34.2
unnamed: R31.2, RV4.3, U2.7
unnamed: C5.1, R12.2, R13.2, U1.2 (-)
unnamed: R10.2, R16.1, U1.5 (+)
unnamed: C5.2, U1.1, U1.10 (+)
unnamed: R11.1, R32.2, R33.1, U1.8, U1.9 (-)
unnamed: C2.1, R6.2, R7.2, U1.13 (-)
unnamed: R2.2, R3.1, U2.3 (+)
unnamed: R33.2, R34.1, U2.5 (+)
unnamed: C7.1, R23.2, R25.2, U2.9 (-)
unnamed: C2.2, U1.14, U2.12 (+)
unnamed: R2.1, R8.2, R9.1, U2.13 (-), U2.14
unnamed: C6.1, R22.2, R24.2, U3.6 (-)
unnamed: C6.2, U3.7, U3.10 (+)
unnamed: R10.1, R26.2, R28.1, U3.8, U3.9 (-)
unnamed: C7.2, U2.8, U3.12 (+)
unnamed: R15.1, R27.2, R29.1, U3.13 (-), U3.14
unnamed: R15.2, R17.1, U4.3 (+)

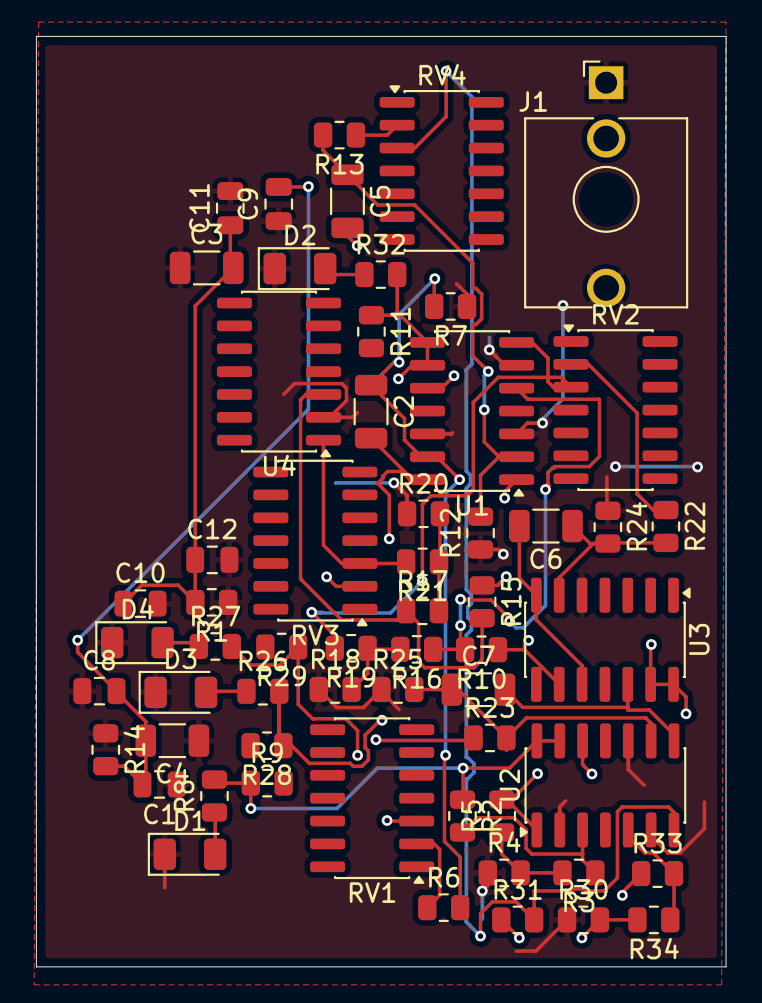
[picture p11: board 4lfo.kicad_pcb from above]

Board: 4 copper layers, 38.3 x 51.7 mm, 59 parts (0 on the bottom side), 35 nets.

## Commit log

2026-01-30 adding the pcb
    [Untitled.kicad_pcb, Untitled.kicad_sch, guitar-input-eg.kicad_pcb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]
2026-05-29 finished the mod synth :D
    (i keep on forgetting to commit :sob:)
    [4lfo.kicad_pcb, 4lfo.kicad_sch, Untitled.kicad_pcb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]
